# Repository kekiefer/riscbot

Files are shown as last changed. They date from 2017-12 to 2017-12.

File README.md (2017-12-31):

# RISCbot

Source files for the LoFive RISC-V RISCbot

## Building software

This project leverages the freedom-e-sdk bsp, and can use a toolchain that is
part of the freedom-e-sdk, or an external toolchain. You must define the
following environment variables to build the project:

```
export BSP_BASE=/my/desired/location/freedom-e-sdk/bsp
export RISCV_OPENOCD_PATH=/my/desired/location/openocd
export RISCV_PATH=/my/desired/location/riscv64-unknown-elf-gcc-<date>-<version>
```

After this, you can build the software as if you were building an example from the sdk:

```
make software upload PROGRAM=riscbot BOARD=freedom-e300-lofive
```

## Hardware design files

The directory `pcb` contains the KiCAD schematics used to prototype RISCbot.
Also included is a board layout that is complete to the best of my knowledge,
but please note that I have not actually fabricated this PCB as RISCbot was
hand-wired on a perforated circuit board.

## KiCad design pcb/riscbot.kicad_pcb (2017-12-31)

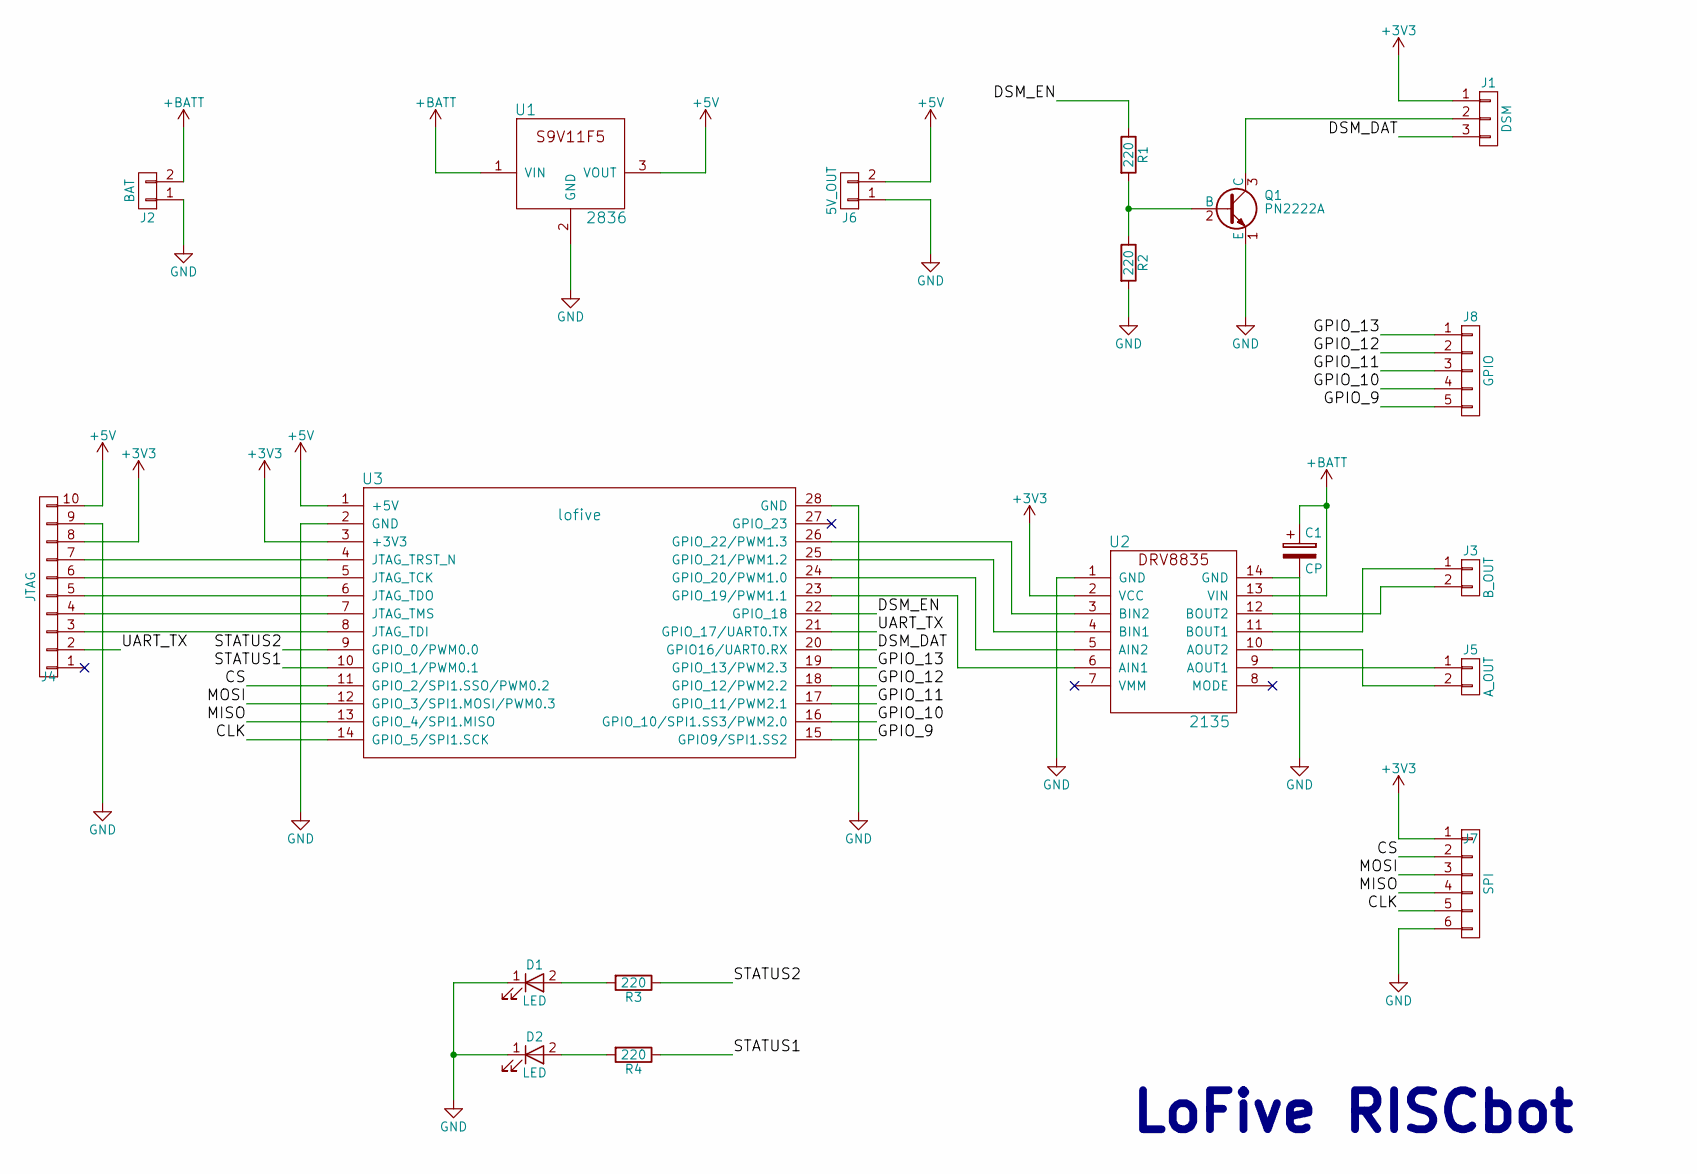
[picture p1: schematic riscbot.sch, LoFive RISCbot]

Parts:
C1: CP; CP_Radial_D5.0mm_P2.50mm
D1, D2: LED; LED_D5.0mm
J1: DSM; Pin_Header_Straight_1x03
J2: BAT; Pin_Header_Straight_1x02
J3: B_OUT; Pin_Header_Straight_1x02
J4: JTAG; Pin_Header_Straight_1x10
J5: A_OUT; Pin_Header_Straight_1x02
J6: 5V_OUT; Pin_Header_Straight_1x02
J7: SPI; Pin_Header_Straight_1x06
J8: GPIO; Pin_Header_Straight_1x05
Q1: PN2222A; TO-92_Inline_Wide
R1, R2, R3, R4: 220; R_Axial_DIN0207_L6.3mm_D2.5mm_P10.16mm_Horizontal
U1: 2836; s9V11f5
U2: 2135; drv8835-rev
U3: lofive

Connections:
+3V3: J1.1, J4.8, J7.1, U2.2 (VCC), U3.3 (+3V3)
+5V: J4.10, J6.2, U1.3 (VOUT), U3.1 (+5V)
+BATT: C1.1, J2.2, U1.1 (VIN), U2.13 (VIN)
/CLK: J7.5, U3.14 (GPIO_5/SPI1.SCK)
/CS: J7.2, U3.11 (GPIO_2/SPI1.SSO/PWM0.2)
/DSM_DAT: J1.3, U3.20 (GPIO16/UART0.RX)
/DSM_EN: R1.1, U3.22 (GPIO_18)
/GPIO_9: J8.5, U3.15 (GPIO9/SPI1.SS2)
/GPIO_10: J8.4, U3.16 (GPIO_10/SPI1.SS3/PWM2.0)
/GPIO_11: J8.3, U3.17 (GPIO_11/PWM2.1)
/GPIO_12: J8.2, U3.18 (GPIO_12/PWM2.2)
/GPIO_13: J8.1, U3.19 (GPIO_13/PWM2.3)
/MISO: J7.4, U3.13 (GPIO_4/SPI1.MISO)
/MOSI: J7.3, U3.12 (GPIO_3/SPI1.MOSI/PWM0.3)
/STATUS1: R4.1, U3.10 (GPIO_1/PWM0.1)
/STATUS2: R3.1, U3.9 (GPIO_0/PWM0.0)
/UART_TX: J4.2, U3.21 (GPIO_17/UART0.TX)
GND: C1.2, D1.1 (K), D2.1 (K), J2.1, J4.9, J6.1, J7.6, Q1.1 (E), R2.2, U1.2 (GND), U2.1 (GND), U2.14 (GND), U3.2 (GND), U3.28 (GND)
unnamed: D1.2 (A), R3.2
unnamed: D2.2 (A), R4.2
unnamed: J1.2, Q1.3 (C)
unnamed: J3.1, U2.11 (BOUT1)
unnamed: J3.2, U2.12 (BOUT2)
unnamed: J4.3, U3.8 (JTAG_TDI)
unnamed: J4.4, U3.7 (JTAG_TMS)
unnamed: J4.5, U3.6 (JTAG_TDO)
unnamed: J4.6, U3.5 (JTAG_TCK)
unnamed: J4.7, U3.4 (JTAG_TRST_N)
unnamed: J5.1, U2.9 (AOUT1)
unnamed: J5.2, U2.10 (AOUT2)
unnamed: Q1.2 (B), R1.2, R2.1
unnamed: U2.3 (BIN2), U3.26 (GPIO_22/PWM1.3)
unnamed: U2.4 (BIN1), U3.25 (GPIO_21/PWM1.2)
unnamed: U2.5 (AIN2), U3.24 (GPIO_20/PWM1.0)
unnamed: U2.6 (AIN1), U3.23 (GPIO_19/PWM1.1)

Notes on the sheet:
LoFive RISCbot

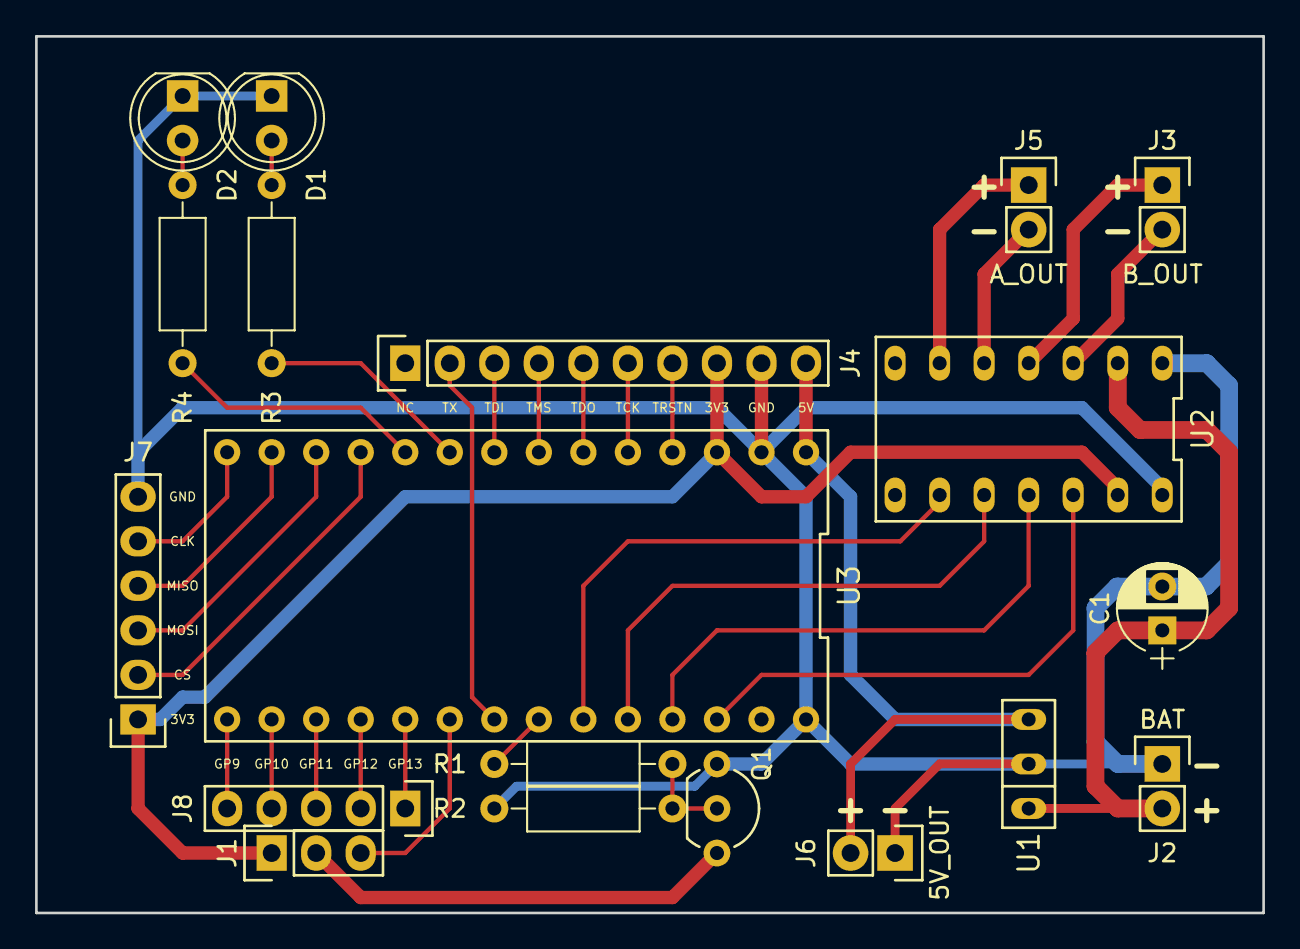
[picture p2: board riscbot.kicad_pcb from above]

Board: 2 copper layers, 70.0 x 50.0 mm, 19 parts (0 on the bottom side), 35 nets.

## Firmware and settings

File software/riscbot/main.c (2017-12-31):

#include <stdio.h>
#include <stdint.h>

#include "platform.h"
#include "encoding.h"

void use_default_clocks();
void use_pll(int refsel, int bypass, int r, int f, int q);
unsigned long long mtime_lo(void);

void init_rc();
void read_rc_frame();

extern void trap_entry();

extern uint16_t rc_data[7];

#define PWM0_OFFSET (19)
#define PWM1_OFFSET (20)
#define PWM2_OFFSET (21)
#define PWM3_OFFSET (22)

#define LED_STAT2_OFFSET (0)
#define LED_STAT1_OFFSET (1)

void led_init()
{
  PWM1_REG(PWM_CFG)   = 0;
  PWM1_REG(PWM_COUNT) = 0;

  PWM1_REG(PWM_CMP0)  = 0;
  PWM1_REG(PWM_CMP1)  = 0;
  PWM1_REG(PWM_CMP2)  = 0;
  PWM1_REG(PWM_CMP3)  = 0;

  PWM1_REG(PWM_CFG)   = (PWM_CFG_ENALWAYS) | (PWM_CFG_DEGLITCH) | 4;

  GPIO_REG(GPIO_IOF_EN )    |= (1 << PWM0_OFFSET) | (1 << PWM1_OFFSET) | (1 << PWM2_OFFSET) | (1 << PWM3_OFFSET);
  GPIO_REG(GPIO_OUTPUT_XOR) |= (1 << PWM0_OFFSET) | (1 << PWM1_OFFSET) | (1 << PWM2_OFFSET) | (1 << PWM3_OFFSET);
  GPIO_REG(GPIO_IOF_SEL)    |= (1 << PWM0_OFFSET) | (1 << PWM1_OFFSET) | (1 << PWM2_OFFSET) | (1 << PWM3_OFFSET);
}

int set_vector(int fwd_rev, int lft_rgt)
{
  int m1, m2;

  m1 = fwd_rev + lft_rgt;
  m2 = fwd_rev - lft_rgt;

  if (m1 > 682)
    m1 = 682;
  else if (m1 < -682)
    m1 = -682;

  if (m2 > 682)
    m2 = 682;
  else if (m2 < -682)
    m2 = -682;

  int m1_16 = 65535 * m1 / 682;

  if (m1_16 < 0) {
    PWM1_REG(PWM_CMP0) = abs(m1_16);
    PWM1_REG(PWM_CMP1) = 0;
  }
  else {
    PWM1_REG(PWM_CMP0) = 0;
    PWM1_REG(PWM_CMP1) = abs(m1_16); // PWM is low on the left, GPIO is low on the left side, LED is ON on the left.
  }

  int m2_16 = 65535 * m2 / 682;

  if (m2_16 < 0) {
    PWM1_REG(PWM_CMP2) = 0;
    PWM1_REG(PWM_CMP3) = abs(m2_16); // PWM is low on the left, GPIO is low on the left side, LED is ON on the left.
  }
  else {
    PWM1_REG(PWM_CMP2) = abs(m2_16);
    PWM1_REG(PWM_CMP3) = 0;
  }
}

gpio_init()
{
  GPIO_REG(GPIO_OUTPUT_VAL) = 0;

  GPIO_REG(GPIO_INPUT_EN) = 0;
  GPIO_REG(GPIO_OUTPUT_EN) = (0x1 << LED_STAT1_OFFSET) | (0x1 << LED_STAT2_OFFSET);

  GPIO_REG(GPIO_OUTPUT_VAL) |= (0x1 << LED_STAT1_OFFSET);
}

int main()
{
  use_default_clocks();
  use_pll(0, 0, 1, 31, 1);

  write_csr(mtvec, &trap_entry);
  if (read_csr(misa) & (1 << ('F' - 'A'))) { // if F extension is present
    write_csr(mstatus, MSTATUS_FS); // allow FPU instructions without trapping
    write_csr(fcsr, 0); // initialize rounding mode, undefined at reset
  }

  gpio_init();

  init_rc();

  led_init();

  while (1)
  {
    read_rc_frame();

#if 0
    // 342 - 1706
    // 1024 +/- 682
    int G = 65535 * (rc_data[0] - 1024) / 682;
    if (G < 0) {
      PWM1_REG(PWM_CMP0) = 0;
      PWM1_REG(PWM_CMP1) = abs(G); // PWM is low on the left, GPIO is low on the left side, LED is ON on the left.
    }
    else {
      PWM1_REG(PWM_CMP0)  = abs(G);
      PWM1_REG(PWM_CMP1) = 0;
    }
#else
    set_vector(rc_data[2] - 1024, -(rc_data[1] - 1024));
#endif
  }

  return 0;
}

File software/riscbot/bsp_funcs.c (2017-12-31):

#include <stdio.h>
#include <stdint.h>

#include "platform.h"
#include "encoding.h"

unsigned long long mtime_lo(void)
{
  return *(volatile unsigned long long *)(CLINT_CTRL_ADDR + CLINT_MTIME);
}

void use_hfrosc(int div, int trim)
{
  // Make sure the HFROSC is running at its default setting
  PRCI_REG(PRCI_HFROSCCFG) = (ROSC_DIV(div) | ROSC_TRIM(trim) | ROSC_EN(1));
  while ((PRCI_REG(PRCI_HFROSCCFG) & ROSC_RDY(1)) == 0) ;
  PRCI_REG(PRCI_PLLCFG) &= ~PLL_SEL(1);
}

void use_pll(int refsel, int bypass, int r, int f, int q)
{
  // Ensure that we aren't running off the PLL before we mess with it.
  if (PRCI_REG(PRCI_PLLCFG) & PLL_SEL(1)) {
    // Make sure the HFROSC is running at its default setting
    use_hfrosc(4, 16);
  }

  // Set PLL Source to be HFXOSC if available.
  uint32_t config_value = 0;

  config_value |= PLL_REFSEL(refsel);

  if (bypass) {
    // Bypass
    config_value |= PLL_BYPASS(1);

    PRCI_REG(PRCI_PLLCFG) = config_value;

    // If we don't have an HFXTAL, this doesn't really matter.
    // Set our Final output divide to divide-by-1:
    PRCI_REG(PRCI_PLLDIV) = (PLL_FINAL_DIV_BY_1(1) | PLL_FINAL_DIV(0));
  } else {
    // In case we are executing from QSPI,
    // (which is quite likely) we need to
    // set the QSPI clock divider appropriately
    // before boosting the clock frequency.

    // Div = f_sck/2
    SPI0_REG(SPI_REG_SCKDIV) = 8;

    // Set DIV Settings for PLL
    // Both HFROSC and HFXOSC are modeled as ideal
    // 16MHz sources (assuming dividers are set properly for
    // HFROSC).
    // (Legal values of f_REF are 6-48MHz)

    // Set DIVR to divide-by-2 to get 8MHz frequency
    // (legal values of f_R are 6-12 MHz)

    config_value |= PLL_BYPASS(1);
    config_value |= PLL_R(r);

    // Set DIVF to get 512Mhz frequncy
    // There is an implied multiply-by-2, 16Mhz.
    // So need to write 32-1
    // (legal values of f_F are 384-768 MHz)
    config_value |= PLL_F(f);

    // Set DIVQ to divide-by-2 to get 256 MHz frequency
    // (legal values of f_Q are 50-400Mhz)
    config_value |= PLL_Q(q);

    // Set our Final output divide to divide-by-1:
    PRCI_REG(PRCI_PLLDIV) = (PLL_FINAL_DIV_BY_1(1) | PLL_FINAL_DIV(0));

    PRCI_REG(PRCI_PLLCFG) = config_value;

    // Un-Bypass the PLL.
    PRCI_REG(PRCI_PLLCFG) &= ~PLL_BYPASS(1);

    // Wait for PLL Lock
    // Note that the Lock signal can be glitchy.
    // Need to wait 100 us
    // RTC is running at 32kHz.
    // So wait 4 ticks of RTC.
    uint32_t now = mtime_lo();
    while (mtime_lo() - now < 4) ;

    // Now it is safe to check for PLL Lock
    while ((PRCI_REG(PRCI_PLLCFG) & PLL_LOCK(1)) == 0) ;
  }

  // Switch over to PLL Clock source
  PRCI_REG(PRCI_PLLCFG) |= PLL_SEL(1);
}

void use_default_clocks()
{
  // Use HFROSC
  use_hfrosc(4, 16);
}

void uart_init(size_t baud_rate)
{
  GPIO_REG(GPIO_IOF_SEL) &= ~IOF0_UART0_MASK;
  GPIO_REG(GPIO_IOF_EN) |= IOF0_UART0_MASK;
  UART0_REG(UART_REG_DIV) = get_cpu_freq() / baud_rate - 1;
  UART0_REG(UART_REG_TXCTRL) |= UART_TXEN;
  UART0_REG(UART_REG_RXCTRL) |= UART_RXEN;
}
